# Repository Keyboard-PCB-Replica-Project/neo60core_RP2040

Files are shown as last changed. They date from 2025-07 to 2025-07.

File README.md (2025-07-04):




NEO60 CORE 레플리카 PCB입니다.

NEO60 CU에 체결이 되기는 하나, 실제 작동하는지는 확인하지 못했습니다.

추후에 확인해보겠습니다!

LED는 따로 부착해두지 않았습니다.

KT-0805W LED를 구입해서 LED 자리에 납땜해주시면 됩니다. 타오바오나 알리에서 같이 주문해주시면 되며,

납땜 난이도는 스위치보다도 못한 수준입니다.

물론 돈이 더 들어도 괜찮다면, LED까지 부착이 된 채로 배송 오는 옵션을 구현해두겠습니다.

추후에 추가될 수도 있습니다.

추가 필요 부품 : KT-0805W LED

작동 확인 여부 : O

----------------------------------------------------------

This is a replica PCB for the NEO60 CORE.

It fits the NEO60 CU, but I haven’t confirmed if it actually works yet.

I’ll test it later.

LEDs are not included.

You can buy KT-0805W LEDs and solder them yourself.

They’re easy to find on Taobao or AliExpress, and soldering them is even easier than switches.

If you're okay with a bit more cost, I might offer a version with the LEDs pre-installed.

It might be updated later.

Extra parts needed: KT-0805W LEDs

Tested and working: verified

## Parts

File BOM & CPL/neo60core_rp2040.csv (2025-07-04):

Value | Reference | Footprint | LCSC Part Number
SW_Push | BOOTSEL1 | XKB_TS-1187A | C318884
100n | C1,C2,C3,C4,C5,C6,C7,C9,C10,C16 | 805 | C28233
1u | C8,C11,C12,C13 | 805 | C28323
15p | C14,C15 | 805 | C1644
D_Small | D1,D2,D3,D4,D5,D6,D7,D8,D9,D10,D11,D12,D13,D14,D15,D16,D17,D18,D19,D20,D21,D22,D23,D24,D25,D26,D27,D28,D29,D30,D31,D32,D33,D34,D35,D36,D37,D38,D39,D40,D41,D42,D43,D44,D45,D46,D47,D48,D49,D50,D51,D52,D53,D54,D55,D56,D57,D58,D59,D60,D61,D62,D63,D64,D66 | SOD-123 | C64898
27.4 | R1,R2 | 805 | C17594
300R | R3 | 805 | C17617
10k | R5 | 805 | C17414
1k | R4, R6 | 805 | C17513
RP2040 | U1 | QFN-56 | C2040
XC6206PxxxMR | U2 | SOT-23 | C5446
W25Q128JVS | U3 | SOIC-8 | C97521
ABM8-272-T3 | Y1 | 3.2x2.5mm | C20625731

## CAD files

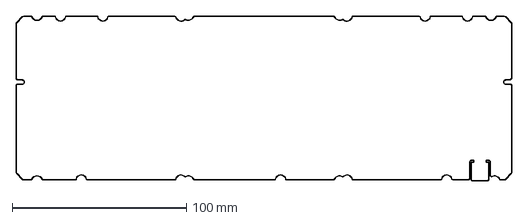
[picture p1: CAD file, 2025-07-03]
OUTLINE.dxf
284.3 x 94.3 mm

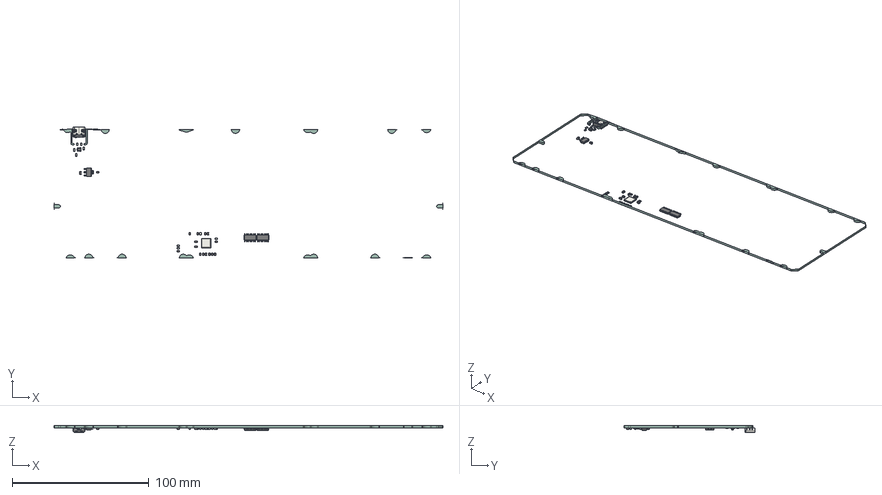
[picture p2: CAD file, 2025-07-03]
neo60core_rp2040.step
284.3 x 95.7 x 4.96 mm
R_0805_2012Metric x 8
C_0805_2012Metric x 16
SOIC_14_39x87mm_P127mm x 2
QFN-56-1EP_7x7mm_Pitch0.4mm
SOT_23_6
SOT_223
Fuse_0805_2012Metric
USB_C_Receptacle_16P_TopMnt_Horizontal_GCT_USB4105-xx-A
63_4_PCB

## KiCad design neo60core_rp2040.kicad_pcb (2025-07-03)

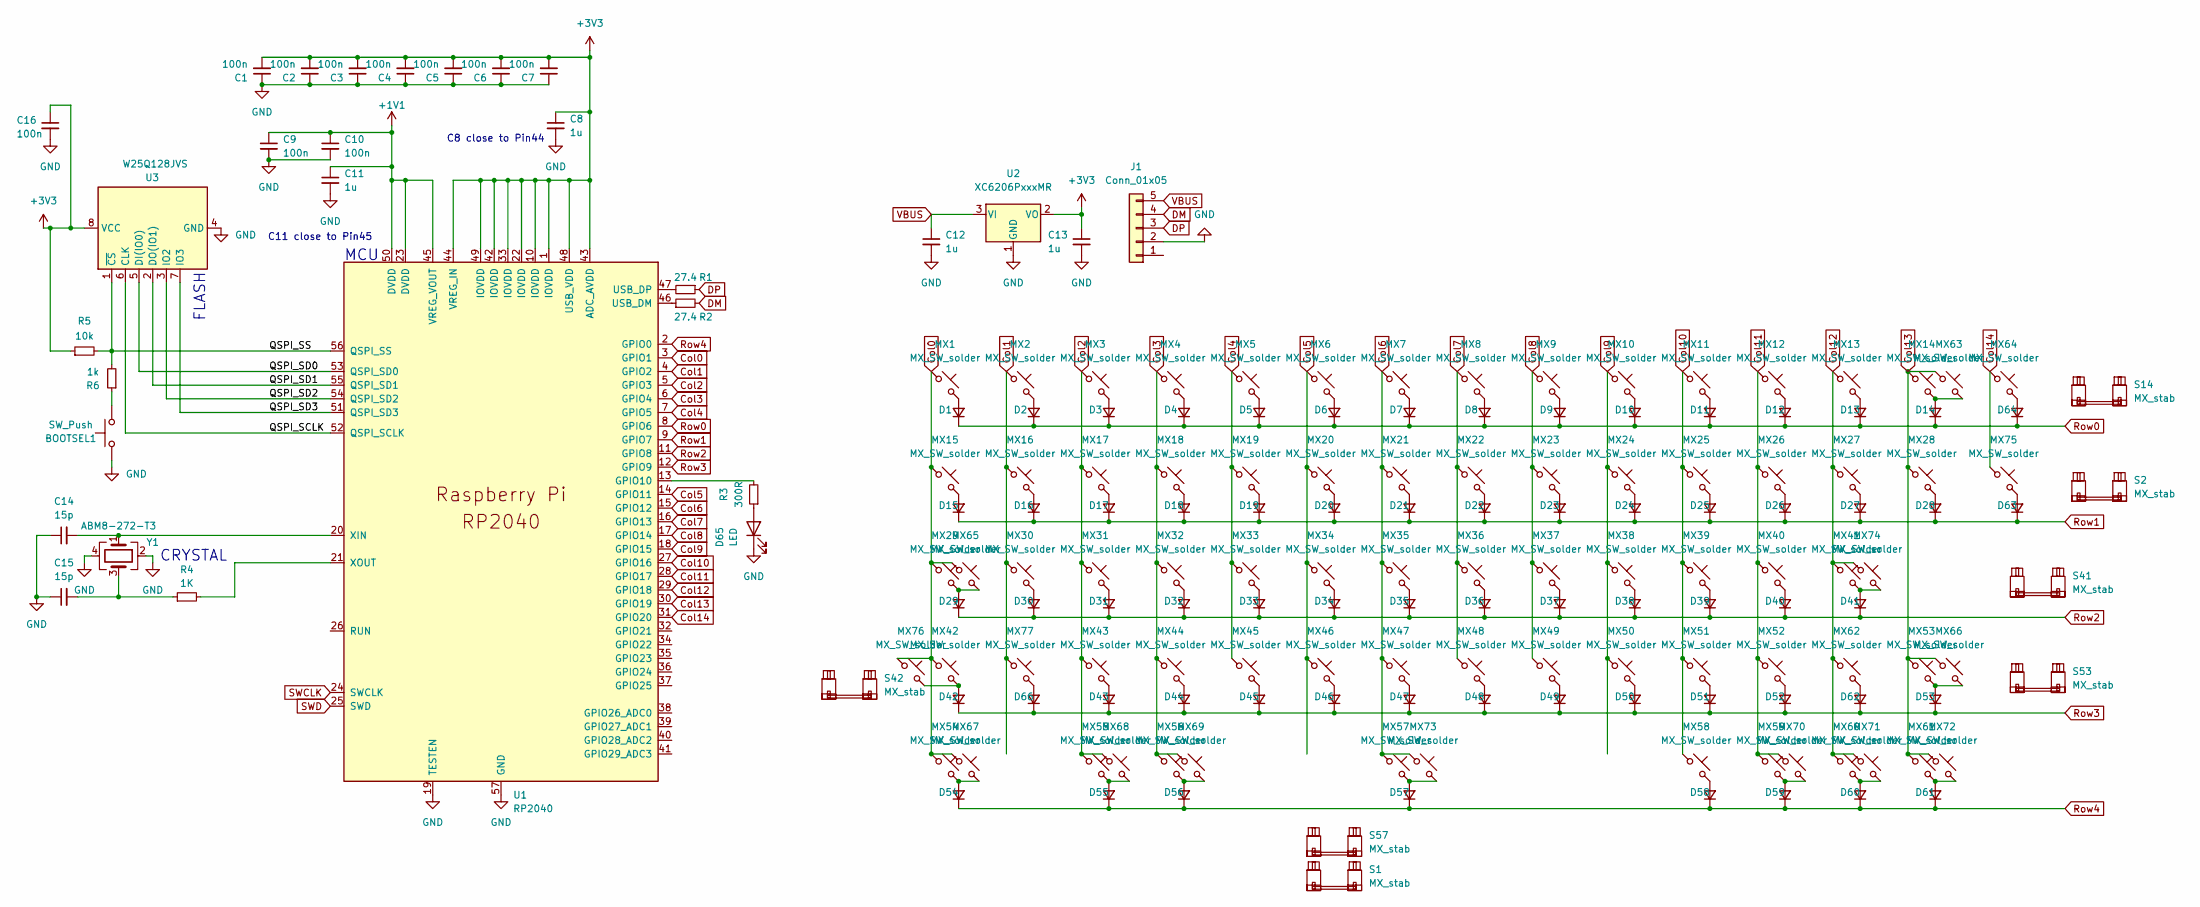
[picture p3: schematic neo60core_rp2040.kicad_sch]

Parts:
BOOTSEL1: SW_Push; SW_Push_1P1T_XKB_TS-1187A
C1, C2, C3, C4, C5, C6, C7, C9, C10, C16: 100n; C_0805_2012Metric
C8, C11, C12, C13: 1u; C_0805_2012Metric
C14, C15: 15p; C_0805_2012Metric
D1, D2, D3, D4, D5, D6, D7, D8, D9, D10, D11, D12, D13, D14, D15, D16, D17, D18, D19, D20, D21, D22, D23, D24, D25, D26, D27, D28, D29, D30, D31, D32, D33, D34, D35, D36, D37, D38, D39, D40, D41, D42, D43, D44, D45, D46, D47, D48, D49, D50, D51, D52, D53, D54, D55, D56, D57, D58, D59, D60, D61, D62, D63, D64, D66: D_Small; Diode_SOD-123_noref
D65: LED; KT-0805W
J1: Conn_01x05; pogo_2.54mm_1x5
MX1, MX2, MX3, MX4, MX5, MX6, MX7, MX8, MX9, MX10, MX11, MX12, MX13, MX14, MX15, MX16, MX17, MX18, MX19, MX20, MX21, MX22, MX23, MX24, MX25, MX26, MX27, MX28, MX29, MX30, MX31, MX32, MX33, MX34, MX35, MX36, MX37, MX38, MX39, MX40, MX41, MX42, MX43, MX44, MX45, MX46, MX47, MX48, MX49, MX50, MX51, MX52, MX53, MX54, MX55, MX56, MX57, MX58, MX59, MX60, MX61, MX62, MX63, MX64, MX65, MX66, MX67, MX68, MX69, MX70, MX71, MX72, MX73, MX74, MX75, MX76, MX77: MX_SW_solder; MX_PCB_1.00u_NoSilkscreen3
R1, R2: 27.4; R_0805_2012Metric
R3: 300R; R_0805_2012Metric
R4: 1K; R_0805_2012Metric
R5: 10k; R_0805_2012Metric
R6: 1k; R_0805_2012Metric
S1: MX_stab; Stabilizer_MX_7.00u
S2, S14, S41, S42, S53: MX_stab; Stabilizer_MX_2.00u
S57: MX_stab; Stabilizer_MX_6.25u
U1: RP2040; RP2040-QFN-56
U2: XC6206PxxxMR; SOT-23
U3: W25Q128JVS; SOIC-8_5.23x5.23mm_P1.27mm
Y1: ABM8-272-T3; Oscillator_SMD_EuroQuartz_XO32-4Pin_3.2x2.5mm

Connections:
+1V1: C9.1, C10.1, C11.1, U1.23 (DVDD), U1.45 (VREG_VOUT), U1.50 (DVDD)
+3V3: C1.2, C2.2, C3.2, C4.2, C5.2, C6.2, C7.2, C8.1, C13.1, C16.1, R5.1, U1.1 (IOVDD), U1.10 (IOVDD), U1.22 (IOVDD), U1.33 (IOVDD), U1.42 (IOVDD), U1.43 (ADC_AVDD), U1.44 (VREG_IN), U1.48 (USB_VDD), U1.49 (IOVDD), U2.2 (VO), U3.8 (VCC)
/QSPI_SCLK: U1.52 (QSPI_SCLK), U3.6 (CLK)
/QSPI_SD0: U1.53 (QSPI_SD0), U3.5 (DI(IO0))
/QSPI_SD1: U1.55 (QSPI_SD1), U3.2 (DO(IO1))
/QSPI_SD2: U1.54 (QSPI_SD2), U3.3 (IO2)
/QSPI_SD3: U1.51 (QSPI_SD3), U3.7 (IO3)
/QSPI_SS: R5.2, R6.2, U1.56 (QSPI_SS), U3.1 (~CS)
Col0: MX1.1, MX15.1, MX29.1, MX42.1, MX54.1, MX65.1, MX67.1, MX76.1, U1.3 (GPIO1)
Col1: MX2.1, MX16.1, MX30.1, MX77.1, U1.4 (GPIO2)
Col2: MX3.1, MX17.1, MX31.1, MX43.1, MX55.1, MX68.1, U1.5 (GPIO3)
Col3: MX4.1, MX18.1, MX32.1, MX44.1, MX56.1, MX69.1, U1.6 (GPIO4)
Col4: MX5.1, MX19.1, MX33.1, MX45.1, U1.7 (GPIO5)
Col5: MX6.1, MX20.1, MX34.1, MX46.1, U1.14 (GPIO11)
Col6: MX7.1, MX21.1, MX35.1, MX47.1, MX57.1, MX73.1, U1.15 (GPIO12)
Col7: MX8.1, MX22.1, MX36.1, MX48.1, U1.16 (GPIO13)
Col8: MX9.1, MX23.1, MX37.1, MX49.1, U1.17 (GPIO14)
Col9: MX10.1, MX24.1, MX38.1, MX50.1, U1.18 (GPIO15)
Col10: MX11.1, MX25.1, MX39.1, MX51.1, MX58.1, U1.27 (GPIO16)
Col11: MX12.1, MX26.1, MX40.1, MX52.1, MX59.1, MX70.1, U1.28 (GPIO17)
Col12: MX13.1, MX27.1, MX41.1, MX60.1, MX62.1, MX71.1, MX74.1, U1.29 (GPIO18)
Col13: MX14.1, MX28.1, MX53.1, MX61.1, MX63.1, MX66.1, MX72.1, U1.30 (GPIO19)
Col14: MX64.1, MX75.1, U1.31 (GPIO20)
DM: J1.4, R2.2
DP: J1.3, R1.1
GND: BOOTSEL1.1, C1.1, C2.1, C3.1, C4.1, C5.1, C6.1, C7.1, C8.2, C9.2, C10.2, C11.2, C12.2, C13.2, C14.1, C15.1, C16.2, D65.1 (K), J1.2, U1.19 (TESTEN), U1.57 (GND), U2.1 (GND), U3.4 (GND), Y1.2, Y1.4
unnamed: BOOTSEL1.2, R6.1
unnamed: C15.2, R4.1, Y1.3
unnamed: D1.2 (A), MX1.2
unnamed: D2.2 (A), MX2.2
unnamed: D3.2 (A), MX3.2
unnamed: D4.2 (A), MX4.2
unnamed: D5.2 (A), MX5.2
unnamed: D6.2 (A), MX6.2
unnamed: D7.2 (A), MX7.2
unnamed: D8.2 (A), MX8.2
unnamed: D9.2 (A), MX9.2
unnamed: D10.2 (A), MX10.2
unnamed: D11.2 (A), MX11.2
unnamed: D12.2 (A), MX12.2
unnamed: D13.2 (A), MX13.2
unnamed: D14.2 (A), MX14.2, MX63.2
unnamed: D15.2 (A), MX15.2
unnamed: D16.2 (A), MX16.2
unnamed: D17.2 (A), MX17.2
unnamed: D18.2 (A), MX18.2
unnamed: D19.2 (A), MX19.2
unnamed: D20.2 (A), MX20.2
unnamed: D21.2 (A), MX21.2
unnamed: D22.2 (A), MX22.2
unnamed: D23.2 (A), MX23.2
unnamed: D24.2 (A), MX24.2
unnamed: D25.2 (A), MX25.2
unnamed: D26.2 (A), MX26.2
unnamed: D27.2 (A), MX27.2
unnamed: D28.2 (A), MX28.2
unnamed: D29.2 (A), MX29.2, MX65.2
unnamed: D30.2 (A), MX30.2
unnamed: D31.2 (A), MX31.2
unnamed: D32.2 (A), MX32.2
unnamed: D33.2 (A), MX33.2
unnamed: D34.2 (A), MX34.2
unnamed: D35.2 (A), MX35.2
unnamed: D36.2 (A), MX36.2
unnamed: D37.2 (A), MX37.2
unnamed: D38.2 (A), MX38.2
unnamed: D39.2 (A), MX39.2
unnamed: D40.2 (A), MX40.2
unnamed: D41.2 (A), MX41.2, MX74.2
unnamed: D42.2 (A), MX42.2, MX76.2
unnamed: D43.2 (A), MX43.2
unnamed: D44.2 (A), MX44.2
unnamed: D45.2 (A), MX45.2
unnamed: D46.2 (A), MX46.2
unnamed: D47.2 (A), MX47.2
unnamed: D48.2 (A), MX48.2
unnamed: D49.2 (A), MX49.2
unnamed: D50.2 (A), MX50.2
unnamed: D51.2 (A), MX51.2
unnamed: D52.2 (A), MX52.2
unnamed: D53.2 (A), MX53.2, MX66.2
unnamed: D54.2 (A), MX54.2, MX67.2
unnamed: D55.2 (A), MX55.2, MX68.2
unnamed: D56.2 (A), MX56.2, MX69.2
unnamed: D57.2 (A), MX57.2, MX73.2
unnamed: D58.2 (A), MX58.2
unnamed: D59.2 (A), MX59.2, MX70.2
unnamed: D60.2 (A), MX60.2, MX71.2
unnamed: D61.2 (A), MX61.2, MX72.2
unnamed: D62.2 (A), MX62.2
unnamed: D63.2 (A), MX75.2
unnamed: D64.2 (A), MX64.2
unnamed: D65.2 (A), R3.1
unnamed: D66.2 (A), MX77.2
unnamed: R3.2, U1.13 (GPIO10)
unnamed: R2.1, U1.46 (USB_DM)
unnamed: R1.2, U1.47 (USB_DP)
unnamed: C14.2, U1.20 (XIN), Y1.1
unnamed: R4.2, U1.21 (XOUT)
Row0: D1.1 (K), D2.1 (K), D3.1 (K), D4.1 (K), D5.1 (K), D6.1 (K), D7.1 (K), D8.1 (K), D9.1 (K), D10.1 (K), D11.1 (K), D12.1 (K), D13.1 (K), D14.1 (K), D64.1 (K), U1.8 (GPIO6)
Row1: D15.1 (K), D16.1 (K), D17.1 (K), D18.1 (K), D19.1 (K), D20.1 (K), D21.1 (K), D22.1 (K), D23.1 (K), D24.1 (K), D25.1 (K), D26.1 (K), D27.1 (K), D28.1 (K), D63.1 (K), U1.9 (GPIO7)
Row2: D29.1 (K), D30.1 (K), D31.1 (K), D32.1 (K), D33.1 (K), D34.1 (K), D35.1 (K), D36.1 (K), D37.1 (K), D38.1 (K), D39.1 (K), D40.1 (K), D41.1 (K), U1.11 (GPIO8)
Row3: D42.1 (K), D43.1 (K), D44.1 (K), D45.1 (K), D46.1 (K), D47.1 (K), D48.1 (K), D49.1 (K), D50.1 (K), D51.1 (K), D52.1 (K), D53.1 (K), D62.1 (K), D66.1 (K), U1.12 (GPIO9)
Row4: D54.1 (K), D55.1 (K), D56.1 (K), D57.1 (K), D58.1 (K), D59.1 (K), D60.1 (K), D61.1 (K), U1.2 (GPIO0)
SWCLK: U1.24 (SWCLK)
SWD: U1.25 (SWD)
VBUS: C12.1, J1.5, U2.3 (VI)

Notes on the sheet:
C11 close to Pin45
MCU
CRYSTAL
C8 close to Pin44
FLASH

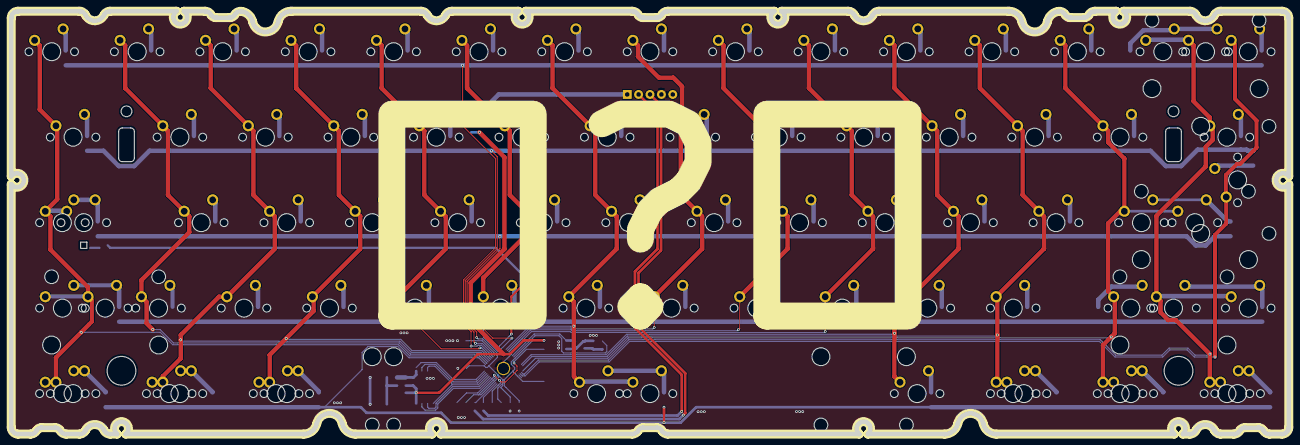
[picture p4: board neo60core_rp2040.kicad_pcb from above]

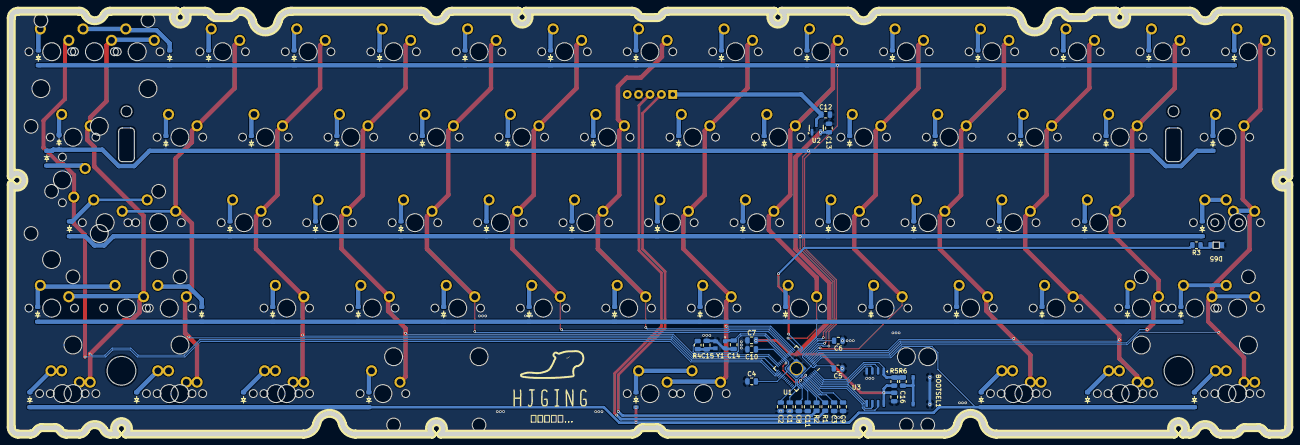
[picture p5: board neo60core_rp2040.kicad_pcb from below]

Board: 2 copper layers, 284.8 x 94.3 mm, 178 parts (93 on the bottom side), 105 nets.
